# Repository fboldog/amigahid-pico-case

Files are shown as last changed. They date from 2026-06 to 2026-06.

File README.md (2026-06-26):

# amigahid-pico case

Parametric two-part snap-fit enclosure for the [**amigahid-pico**](https://github.com/borb/amigahid-pico/) PCB.

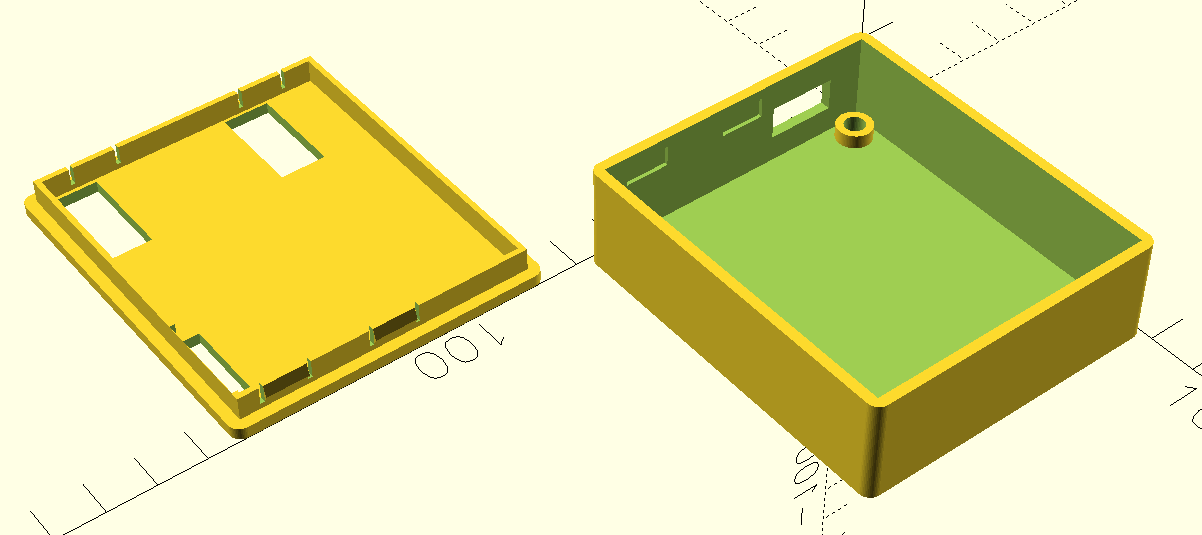
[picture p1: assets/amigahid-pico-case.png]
Screenshot of the case


(LLM involved in the case generation, because of my curiosity. (What can be done with proper instructions?)

---

## Prerequisites

- **OpenSCAD** — rendering, preview, and `.csg`/`.stl` export.
- **FreeCAD** — converting the OpenSCAD CSG into a STEP.

---

## Views

The model has a `view` parameter selecting what gets rendered. Override it from the
command line with `-D 'view="..."'` (no need to edit the file):

| `view` | Purpose |
| --- | --- |
| `print` *(default)* | Both parts laid flat for printing — lid flipped lip-up. |
| `parts` | Shell + lid upright, side by side. **Use this for STEP export.** |
| `assembled` | Lid mated onto the shell. |

---

## OpenSCAD — render and export

**Export an STL** (e.g. straight-to-slicer, print layout):

```sh
"$OPENSCAD" -o /tmp/case-print.stl amigahid-pico-case.scad
```

**Export the CSG** needed for the STEP pipeline — use the `parts` view so the two
solids come out upright and cleanly separated:

```sh
"$OPENSCAD" -o /tmp/check.csg -D 'view="parts"' amigahid-pico-case.scad
```

**Render a preview PNG** (handy for sanity-checking a change):

```sh
"$OPENSCAD" -o /tmp/preview.png --imgsize=1200,900 -D 'view="assembled"' amigahid-pico-case.scad
```

---

## FreeCAD — convert CSG → STEP

OpenSCAD's own STEP export is mesh-based; FreeCAD's `importCSG` instead rebuilds
the geometry as a true B-rep (mathematically round cylinders, exact planes), which
is what you want for CAD reuse. The helper scripts live in `tools/`:

**1. Export the STEP** — `tools/to_step.py` opens the CSG, recomputes, and exports the
top-level solid(s):

```sh
"$FREECAD_CLI" tools/to_step.py /tmp/check.csg amigahid-pico-case.step
```

The script reports any failed objects and the top-level solid count/volume. The
`Recompute failed` lines it prints for intermediate nodes are harmless as long as
`FAILED objects: none` and the final object reports `valid=True`.

**2. Verify the STEP** — `tools/verify_step.py` reports solids, face counts, bounding
box, and per-solid volume:

```sh
"$FREECAD_CLI" tools/verify_step.py amigahid-pico-case.step
```

Expected: **2 solids** (shell + lid), both `valid=True`.

---

## End-to-end: regenerate the STEP after editing the SCAD

```sh

# 1. SCAD -> CSG (parts view)
"$OPENSCAD" -o /tmp/check.csg -D 'view="parts"' amigahid-pico-case.scad

# 2. CSG -> STEP
"$FREECAD_CLI" tools/to_step.py /tmp/check.csg amigahid-pico-case.step

# 3. Verify the result
"$FREECAD_CLI" tools/verify_step.py amigahid-pico-case.step
```

### Optional: confirm no features were dropped

The CSG importer is robust but worth spot-checking after structural edits. Render
the same `parts` view to STL, measure its mesh volume, and compare to the STEP's
solid volume — they should match within rounding (~1 mm³):

```sh
"$OPENSCAD" -o /tmp/check.stl -D 'view="parts"' amigahid-pico-case.scad
"$FREECAD_CLI" tools/mesh_vol.py /tmp/check.stl        # OpenSCAD mesh volume
"$FREECAD_CLI" tools/verify_step.py amigahid-pico-case.step   # STEP solid volume(s)
```

A large mismatch means a feature failed to import — re-check the
`to_step.py` output for failed objects.

---

## Printing notes

- Material: **PETG** (the snap lip flexes; PETG tolerates the relief slits well).
- Mounting: **2× M3 (Voron standard) heat-set inserts**.
  Print orientation is built into the `print` view: the lid comes out lip-up so
  the snap bumps' 45° retention bevels print without overhang.
- After a test print, the main tuning knobs in the SCAD are `pcb_clearance`
  (board fit), the `snap_*` group (snap feel/retention), and the `usba_*` group
  (`usba_height` / `usba_z_above_pcb` for the USB-A opening size and height).

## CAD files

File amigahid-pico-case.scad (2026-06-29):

// amigahid-pico case
// Two-part snap-fit enclosure: bottom shell + top lid
//
// PCB dimensions from KiCad Edge.Cuts layer:
//   Board: 61.722 x 72.39 mm
//   Front notch (RPi Pico USB cable): x 19.94-27.05 mm, 3.81 mm deep
//
// Connectors (positions taken from connector BODY centres in the .kicad_pcb):
//   USB-A Molex 67643 Horizontal  -> front wall cutout (body overhangs front edge)
//   IDC 2x5 x2 (Amiga ports)     -> top lid windows (long axis along Y)
//   PinHeader 1x08 vertical       -> top lid window (long axis along Y)
//   RPi Pico micro-USB            -> internal, no opening (firmware only)
//   PinHeader 1x04 vertical       -> internal, no opening (future display)
//   PinHeader 1x06 horizontal     -> internal, no opening (debug pins)
//
// PCB mounting: 2 bosses for M3 x 5 x 4 Voron heat-set inserts (4.4 mm holes);
// PCB screws down from above with M3 screws. Lid is snap-only (no lid screws).
//
// Closure: 4 snap-fit wedge bumps on the lid's CONTINUOUS alignment lip
// (2 front wall, 2 back wall). Each bump is a sturdy wedge backed by the full
// lip wall (no thin breakable tip). Short relief slits beside each bump stop
// below the top rim, so the lip edge stays continuous while the bump segment
// can flex to snap into a blind pocket on the inner wall face. Exterior stays
// smooth.

// Curve resolution (built-in OpenSCAD specials -- names are fixed, can't rename).
// Together they set how finely every cylinder/arc here (bosses, studs, corners)
// is faceted; OpenSCAD uses whichever yields FEWER fragments (min 5 per circle).
$fa = 4;     // max angle per facet, degrees  -> a circle gets at most 360/4 = 90 sides
$fs = 0.3;   // min facet edge length, mm      -> arc segments never shorter than 0.3 mm
// (Defaults are 12 / 2, which would leave the 4.4 mm insert bores visibly faceted
//  and slightly undersized between facets -> these tighter values keep bores round.
//  Affects only the STL/CSG mesh; FreeCAD rebuilds true round B-rep for the STEP.)

// ── PCB ──────────────────────────────────────────────────────────────────────
pcb_width     = 61.722;
pcb_depth     = 72.390;
pcb_thickness = 1.600;
pcb_clearance = 0.5;    // clearance per side between PCB edge and cavity wall

// ── Case walls ────────────────────────────────────────────────────────────────
wall_thickness  = 2.2;
floor_thickness = 3.0;   // thick enough to host the insert blind hole + ~1 mm base
lid_thickness   = 2.5;

pcb_clear_below = 3.0;   // gap below PCB (back-side SMD + insert boss depth)
pcb_clear_above = 14.5;  // gap above PCB (IDC headers ~12 mm)
corner_radius   = 2.5;
// 45deg chamfer breaking the outer perimeter edge that meets the print bed: the
// shell's BOTTOM edge and the lid plate's TOP edge (the lid prints flipped, so its
// top face is bed-down too). Knocks off the sharp first-layer edge / elephant foot.
edge_chamfer    = 0.4;

// ── USB-A front-wall opening (Molex 67643 horizontal) ───────────────────────
usba_cx           = 47.50;  // connector body centre, PCB-relative X (mirrored via board_x())
usba_width        = 14.5;   // opening width  (X)
usba_height       = 7.0;    // opening height (Z) -- verify vs connector datasheet
usba_z_above_pcb  = 4.6;    // opening centre, height above the PCB top face (raise to taste)

// ── Alignment lip (continuous; centres lid and carries the snap bumps) ───────
lip_height         = 5.0;   // lip depth (hangs down from lid into shell)
lip_gap            = 0.20;  // clearance: lip outer face <-> inner wall face
lip_wall_thickness = 1.2;   // lip wall thickness

// ── Heat-set insert bosses (Voron M3 x 5 x 4: L=4.0, D1=5.0, D2=4.4, W=1.6) ──
insert_length     = 4.0;    // insert length
insert_bore_dia   = 4.4;    // melt/press hole diameter (CNC Kitchen spec)
insert_wall_min   = 1.6;    // min wall around the insert
insert_hole_depth = 5.0;    // blind hole depth from PCB-rest plane (L + 1 mm)

boss_height       = pcb_clear_below;                    // boss height above floor (PCB stand-off)
boss_radius_outer = insert_bore_dia/2 + insert_wall_min; // 3.8 mm -> 7.6 mm boss OD
boss_radius_inner = insert_bore_dia/2;                  // 2.2 mm -> 4.4 mm bore
// floor left below the bore = floor_thickness + pcb_clear_below - insert_hole_depth = 1.0 mm

// M3 mounting holes (PCB-relative)
mount_holes = [[57.785, 3.937], [57.785, 68.453]];

// ── PCB support studs (no insert; mirror the bosses on the opposite side) ────
stud_radius     = 2.5;
// The front stud lands beneath the 1x08 header and fouls its legs. Shift it
// toward the USB-A wall (-X) by this much to clear them. (Back stud unaffected.)
stud_usba_offset = 5.0;

// ── Derived ───────────────────────────────────────────────────────────────────
cavity_width  = pcb_width + 2 * pcb_clearance;   // interior cavity footprint (PCB + clearance)
cavity_depth  = pcb_depth + 2 * pcb_clearance;
outer_width   = cavity_width + 2 * wall_thickness;
outer_depth   = cavity_depth + 2 * wall_thickness;
shell_height  = floor_thickness + pcb_clear_below + pcb_thickness + pcb_clear_above;

pcb_x0 = wall_thickness + pcb_clearance;   // PCB nominal origin (board is located by the bosses)
pcb_y0 = wall_thickness + pcb_clearance;

// KiCad is Y-down and its STEP exporter negates Y. We keep the case oriented
// with USB-A on the front wall, so the board sits 180deg-rotated vs the KiCad
// STEP frame -> every board-referenced X is mirrored through board_x().
function board_x(x_rel) = pcb_x0 + pcb_width - x_rel;

// Lip footprint (nests inside the cavity with lip_gap clearance)
lip_x0     = wall_thickness + lip_gap;
lip_y0     = wall_thickness + lip_gap;        // front lip outer face
lip_width  = cavity_width - 2 * lip_gap;
lip_depth  = cavity_depth - 2 * lip_gap;
lip_y_back = lip_y0 + lip_depth;              // back lip outer face

// ── Snap-fit wedge bump ───────────────────────────────────────────────────────
//
//  A wedge bump sits on the OUTER face of the (continuous) lip wall and snaps
//  into a blind pocket on the inner wall face. The bump is wide and solid,
//  backed by the lip behind it, so there is no thin free-standing tip to break.
//  Cross-section (wall-normal / vertical), front wall shown:
//
//      interior                       | wall |
//        lip wall ||                  |      |
//                 ||                  |      |
//                 ||___               |======|
//                 ||   \  shelf  ----->] POCKET   (catches the pocket top edge)
//                 ||    |  tip        ]      |
//                 ||___/  ramp        |======|
//                 ||                  |      |  ramp = lead-in as lid descends
//
//  Relief slits flank each bump (stopping slit_top_band below the top rim) so the
//  bump segment flexes inward to snap, while the rim stays continuous.
//
//  Insertion: push lid down; the wall's top inner edge rides the ramp, flexing
//             the bump segment inward until the bump drops into the pocket.
//  Retention: the catch corner sits under the pocket's top edge -> blocks lift-off.
//  Release:   press the lip inward at the bump to disengage.

snap_width        = 9.0;    // bump width along the wall (X)
snap_protrusion   = 0.7;    // bump protrusion toward the wall
snap_ramp_rise    = 2.4;    // ramp rise -> lead-in angle = atan(snap_protrusion/snap_ramp_rise) ~= 16 deg
snap_catch_height = 1.0;    // height of the retention bevel
slit_width        = 0.9;    // relief slit width
slit_top_band     = 1.2;    // continuous lip band left above the slits (rim stays whole)

// Blind pocket in the inner wall face
snap_pocket_depth = 0.8;            // < wall (leaves ~1.4 mm of wall)
snap_pocket_width = snap_width + 0.6; // width tolerance
seat_clearance    = 0.10;           // vertical seating clearance

// Pocket vertical extents in SHELL coords (lid plate bottom seats at z = shell_height).
// The bump's retention bevel makes its catch CORNER sit snap_protrusion below the
// lip-face top (zt). Align the pocket ceiling to that corner so a seated lid has only
// seat_clearance of vertical play. (Previously the ceiling sat snap_protrusion too
// high, so the lid could lift ~snap_protrusion before the corner engaged -> "loose".)
catch_corner_z_local = -lip_height + snap_ramp_rise + snap_catch_height - snap_protrusion; // bump catch corner (lid-local)
snap_pocket_z_top    = shell_height + catch_corner_z_local + seat_clearance;
snap_pocket_height   = snap_ramp_rise + snap_catch_height + 1.0;
snap_pocket_z_bot    = snap_pocket_z_top - snap_pocket_height;

// Clip centre X positions (avoid corners and connector cutouts).
// After the X-mirror the front USB-A opening sits at case-X ~9-24, so the front
// clips live to the right of it; the back wall is clear.
clip_x_front = [32, 55];
clip_x_back  = [outer_width * 0.22, outer_width * 0.78];
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

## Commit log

2026-06-26 Initial public version of the case
    [amigahid-pico-case.scad]
2026-06-26 chore(docs): add amigahid-pico link
2026-06-29 bugfix(stud): the stud under the 1x08 pin connector hits the pins, offsete by 5mm to the usb-a connector
    [amigahid-pico-case.scad]
2026-06-29 feature(case): add chamfered edges, the hull bugged at step conversion
    [amigahid-pico-case.scad]
